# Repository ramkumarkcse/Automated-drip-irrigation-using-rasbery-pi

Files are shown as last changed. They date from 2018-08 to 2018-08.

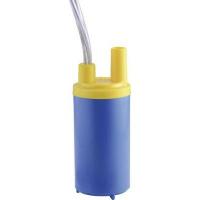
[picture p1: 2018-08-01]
images/water_pump_Barwig_BW04.jpg

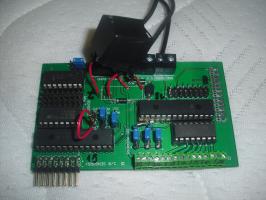
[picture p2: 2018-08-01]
images/pcb_sec_small.jpg

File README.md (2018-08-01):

# Automated-drip-irrigation-using-rasbery-pi
Introduction 

It is an automated system designed to take good care of your plants while you travel for a long time.The propose is to keep track of humidity levels and once in a while drip some water in your plants if they feel thirst. 

How the system works 

The concept is very simple, the system is composed by the following hardware:      

Arduino (I use the pro mini since it's tiny and you can weld according to your needs)      
Raspberry Pi as an interface to arduino (read sensors, upload new hex files if needed)      
Sensors      
Tiny pump      
Bucket with water      
Gardena micro dipping system      
Android phone to check the status of your plants 

The whole system is controlled by the arduino microcontroller. It checks the humidity sensors every cycle and sets a variable to true or false in case the sole conditions and amount of water on it. If it's dryi, according to a predefined threshold, it will drip water for few seconds or until the sole turns to hidratate enough.

How to use it

Import the Arduino file into an arduino IDE     
Import the android project to your IDE (I use eclipse)     
Copy the bridge file tcp_server.py into your raspberry Pi and set it up under your /etc/rc.local by adding the following line: (sleep 10;python /path/where/you/copied/tcp_server.py)&amp;

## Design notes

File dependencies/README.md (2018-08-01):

required dependencies fo YawsPi

in directory 'downloaded by pip' are packages downloaded by commad:
pip install --download="~" PACKAGENAME

file pygal.js-gh-pages.zip is downloaded form github, contains java scripts not required, but
usefull for nice pygal charts

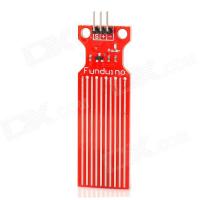
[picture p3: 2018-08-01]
images/water_level_sensor_funduino.jpg

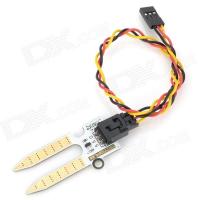
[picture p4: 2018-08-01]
images/water_level_sensor_octopus_soil_humidity.jpg

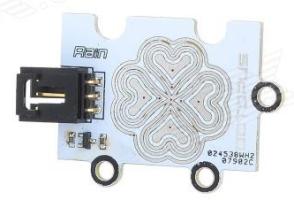
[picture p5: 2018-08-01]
images/rain_sensor_Octopus.jpg

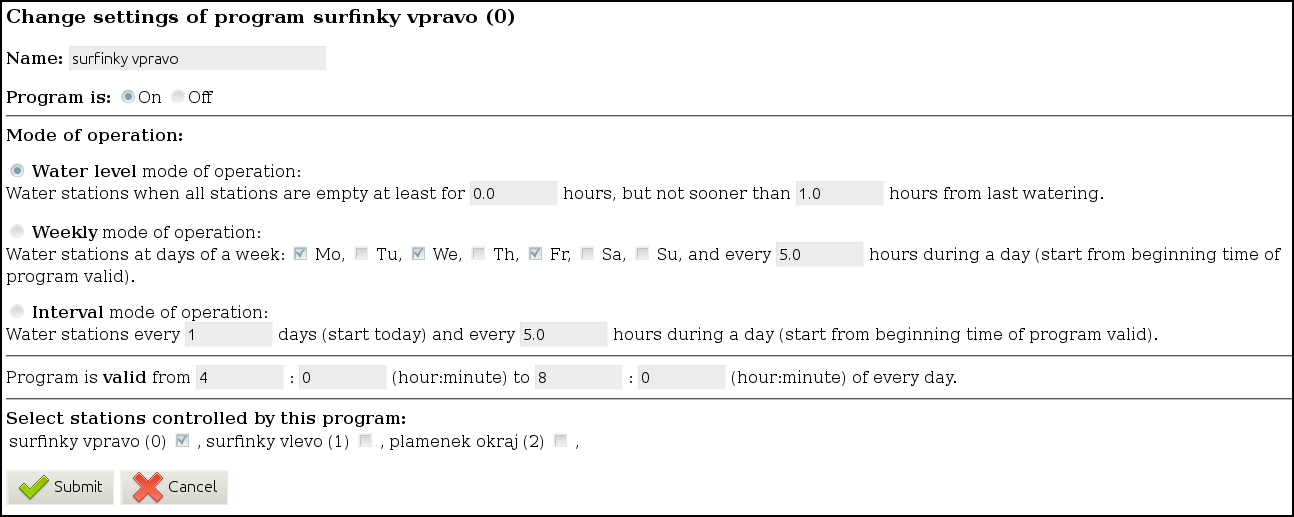
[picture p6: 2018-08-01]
images/webpage-programs-settings-brdr.png

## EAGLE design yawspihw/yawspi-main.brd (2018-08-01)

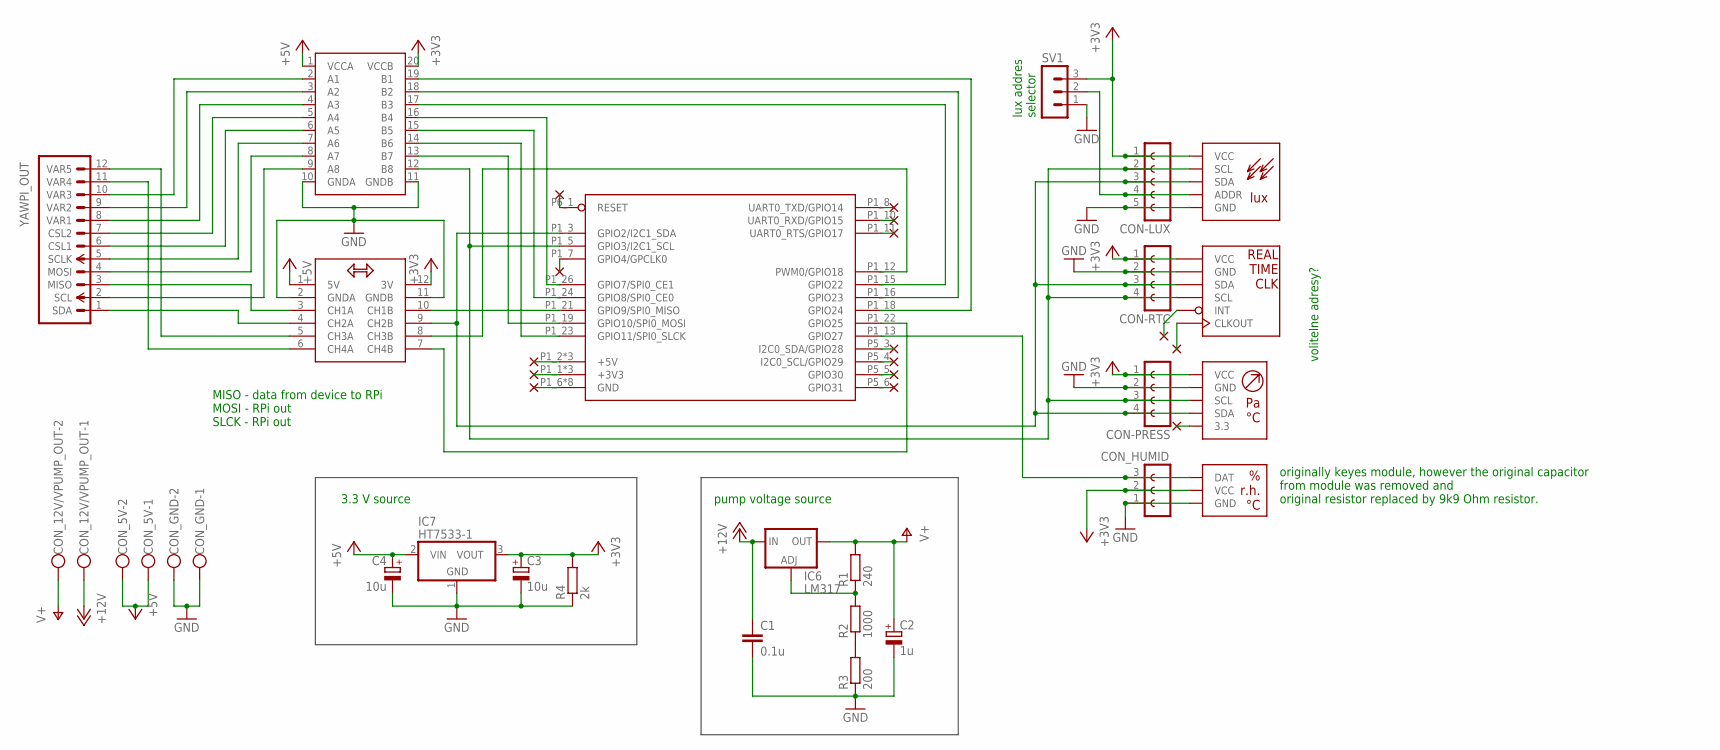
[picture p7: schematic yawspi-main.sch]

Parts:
C1: 0.1u; C025-025X050
C2: 1u; E2,5-6E
C3, C4: 10u; E2,5-5
CON-LUX: FE05-1
CON-PRESS: FE04-1
CON-RTC: FE04-1
CON_5V, CON_12V/VPUMP_OUT: W237-102
CON_GND: W237-102
CON_HUMID: FE03-1
IC6: LM317; 317TS
IC7: HT7533-1; TO92
R1: 240; 0204V
R2: 1000; 0204V
R3: 200; 0204V
R4: 2k; 0204V
SV1: MA03-1
U$1: RPI-B-V2HOLES; RPI-B-V2-HOLES
U$2: BIDIR_CONVERSION_MODULE
U$3: LEVEL_CONVERSION_MODULE
YAWPI_OUT: CON-YAWPI-OUT; MA12-1

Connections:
+3V3: C3.+, CON-LUX.1, CON-PRESS.1, CON-RTC.1, CON_HUMID.2, IC7.3 (VOUT), R4.2, SV1.3, U$2.12 (3V), U$3.20 (VCCB)
+5V: C4.+, CON_5V.1, CON_5V.2, IC7.2 (VIN), U$2.1 (5V), U$3.1 (VCCA)
+12V: C1.1, CON_12V/VPUMP_OUT.1, IC6.3 (IN)
GND: C1.2, C2.-, C3.-, C4.-, CON-LUX.5, CON-PRESS.2, CON-RTC.2, CON_GND.1, CON_GND.2, CON_HUMID.1, IC7.1 (GND), R3.1, R4.1, SV1.1, U$2.2 (GNDA), U$2.11 (GNDB), U$3.10 (GNDA), U$3.11 (GNDB)
MOSI: U$1.P1_19 (GPIO10/SPI0_MOSI), U$3.13 (B7)
unnamed: U$3.9 (A8), YAWPI_OUT.2 (SCL)
unnamed: U$3.6 (A5), YAWPI_OUT.6 (CSL1)
unnamed: U$2.4 (CH2A), YAWPI_OUT.1 (SDA)
unnamed: U$1.P1_21 (GPIO9/SPI0_MISO), U$2.10 (CH1B)
unnamed: U$3.7 (A6), YAWPI_OUT.5 (SCLK)
unnamed: U$3.8 (A7), YAWPI_OUT.4 (MOSI)
unnamed: U$2.3 (CH1A), YAWPI_OUT.3 (MISO)
unnamed: U$3.5 (A4), YAWPI_OUT.7 (CSL2)
unnamed: U$1.P1_12 (PWM0/GPIO18), U$2.8 (CH3B)
unnamed: U$1.P1_22 (GPIO25), U$2.7 (CH4B)
unnamed: U$3.4 (A3), YAWPI_OUT.8 (VAR1)
unnamed: U$3.3 (A2), YAWPI_OUT.9 (VAR2)
unnamed: U$3.2 (A1), YAWPI_OUT.10 (VAR3)
unnamed: U$2.6 (CH4A), YAWPI_OUT.11 (VAR4)
unnamed: U$2.5 (CH3A), YAWPI_OUT.12 (VAR5)
unnamed: U$1.P1_24 (GPIO8/SPI0_CE0), U$3.15 (B5)
unnamed: U$1.P1_26 (GPIO7/SPI0_CE1), U$3.16 (B4)
unnamed: U$1.P1_15 (GPIO22), U$3.17 (B3)
unnamed: U$1.P1_16 (GPIO23), U$3.18 (B2)
unnamed: U$1.P1_18 (GPIO24), U$3.19 (B1)
unnamed: CON_HUMID.3, U$1.P1_13 (GPIO27)
unnamed: U$1.P1_6 (GND), U$1.P1_9 (GND), U$1.P1_14 (GND), U$1.P1_20 (GND), U$1.P1_25 (GND), U$1.P5_7 (GND), U$1.P5_8 (GND), U$1.P6_2 (GND)
unnamed: CON-LUX.4, SV1.2
unnamed: U$1.P1_2 (+5V), U$1.P1_4 (+5V), U$1.P5_1 (+5V)
unnamed: U$1.P1_1 (+3V3), U$1.P1_17 (+3V3), U$1.P5_2 (+3V3)
unnamed: IC6.1 (ADJ), R1.1, R2.2
unnamed: R2.1, R3.2
SCL: CON-LUX.2, CON-PRESS.3, CON-RTC.4, U$1.P1_5 (GPIO3/I2C1_SCL), U$3.12 (B8)
SDA: CON-LUX.3, CON-PRESS.4, CON-RTC.3, U$1.P1_3 (GPIO2/I2C1_SDA), U$2.9 (CH2B)
SLCK: U$1.P1_23 (GPIO11/SPI0_SLCK), U$3.14 (B6)
V+: C2.+, CON_12V/VPUMP_OUT.2, IC6.2 (OUT), R1.2

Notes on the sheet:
3.3 V source
MISO - data from device to RPi MOSI - RPi out SLCK - RPi out
pump voltage source
volitelne adresy?
lux addres selector
originally keyes module, however the original capacitor from module was removed and original resistor replaced by 9k9 Ohm resistor.

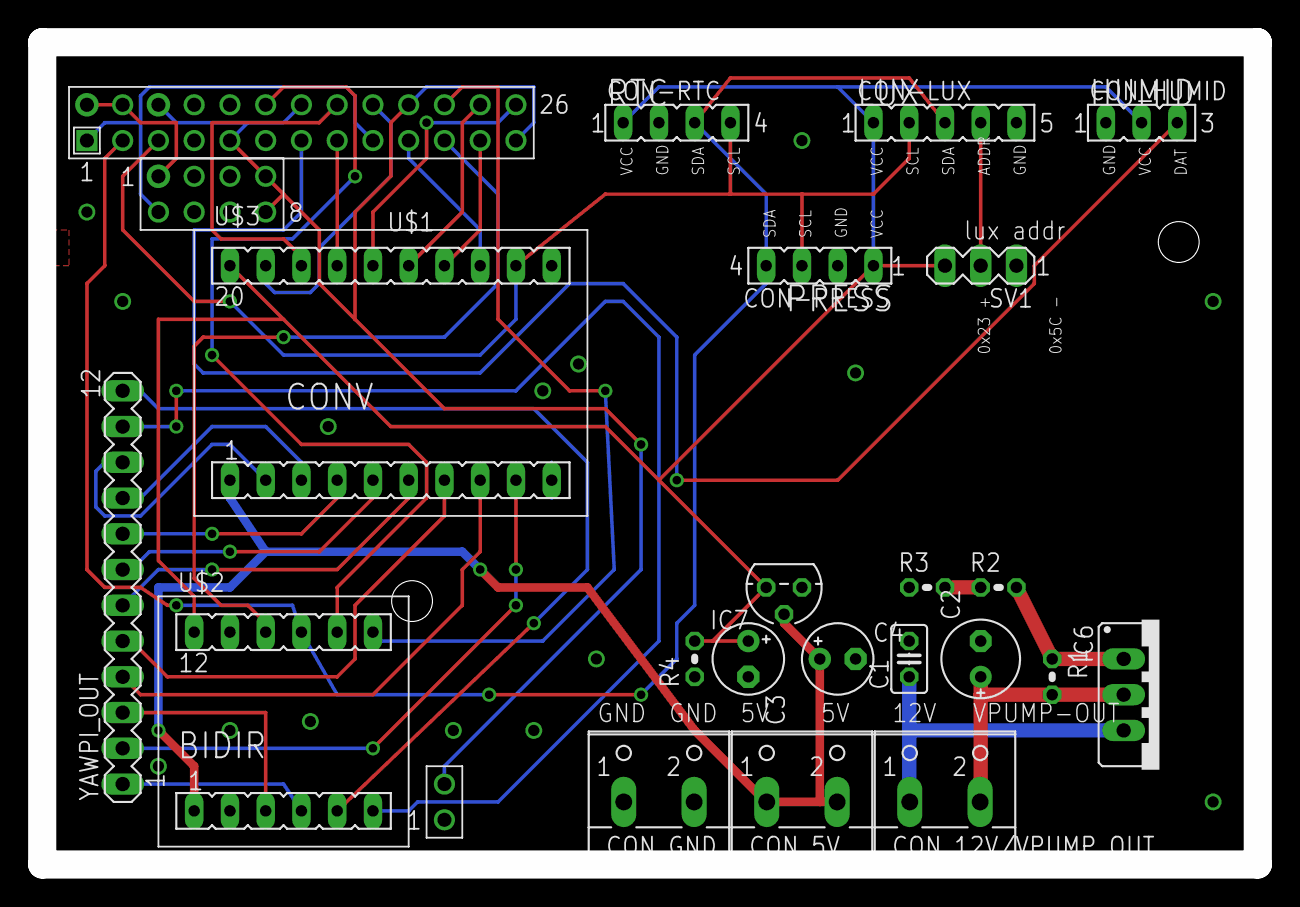
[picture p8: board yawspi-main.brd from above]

Board: 2 copper layers, 86.4 x 58.4 mm, 22 parts (0 on the bottom side), 36 nets.

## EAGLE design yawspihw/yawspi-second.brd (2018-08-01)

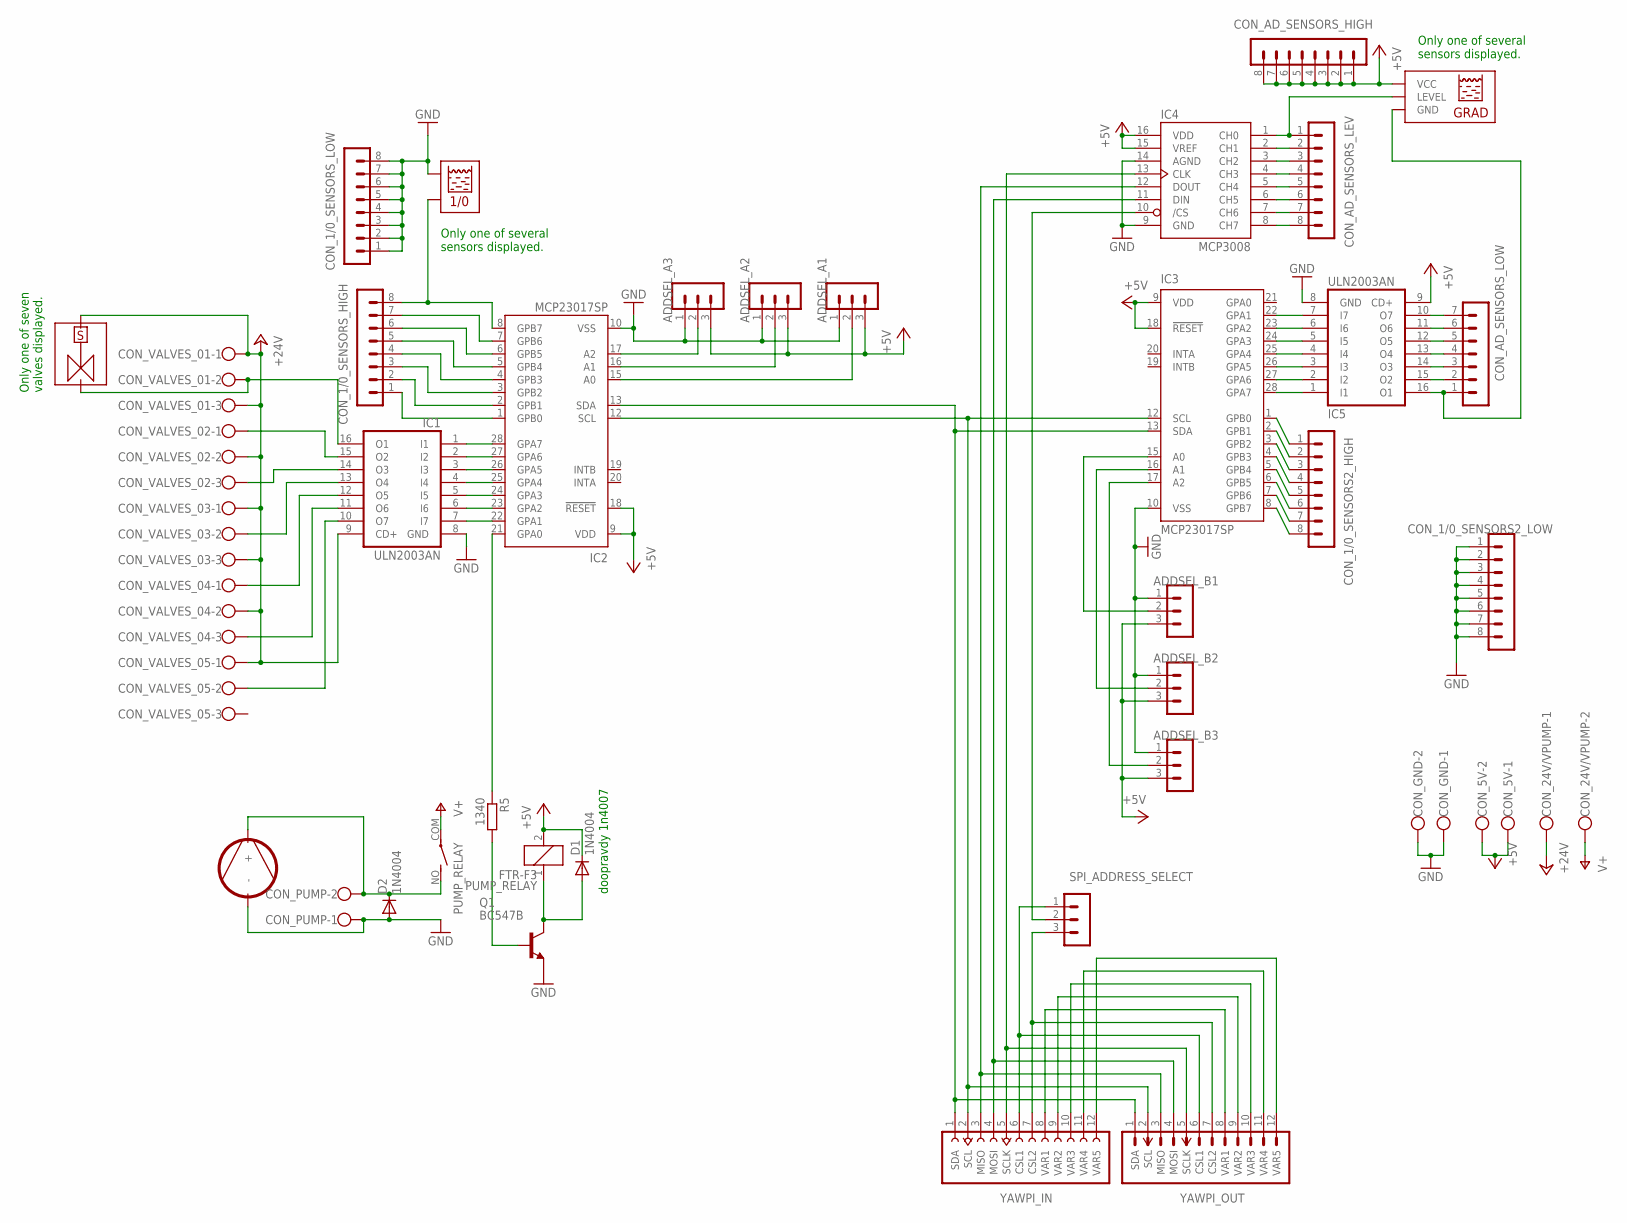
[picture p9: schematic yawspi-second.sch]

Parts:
ADDSEL_A1, ADDSEL_A2, ADDSEL_A3: MA03-1
ADDSEL_B1, ADDSEL_B2, ADDSEL_B3: MA03-1
CON_1/0_SENSORS2_HIGH, CON_1/0_SENSORS2_LOW, CON_1/0_SENSORS_HIGH, CON_1/0_SENSORS_LOW: MA08-1_SHORTPAD
CON_5V, CON_24V/VPUMP: W237-102
CON_AD_SENSORS_HIGH: MA08-1_SHORTPAD
CON_AD_SENSORS_LEV: MA08-1_SHORTPAD
CON_AD_SENSORS_LOW: MA07-1_SHORTPAD
CON_GND: W237-102
CON_PUMP: W237-102
CON_VALVES_01, CON_VALVES_02, CON_VALVES_03, CON_VALVES_04, CON_VALVES_05: W237-102-SMALL
D1, D2: 1N4004; DO41-10
IC1, IC5: ULN2003AN; DIL16
IC2, IC3: MCP23017SP; DIL28-3
IC4: MCP3008; DIL16
PUMP_RELAY: FTR-F3; FTR-F3_PACKAGE
Q1: BC547B; TO92
R5: 1340; 0204/7
SPI_ADDRESS_SELECT: MA03-1
YAWPI_IN: CON-YAWPI-IN; FE12
YAWPI_OUT: CON-YAWPI-OUT; MA12-1

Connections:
+5V: ADDSEL_A1.3, ADDSEL_A2.3, ADDSEL_A3.3, ADDSEL_B1.3, ADDSEL_B2.3, ADDSEL_B3.3, CON_5V.1, CON_5V.2, CON_AD_SENSORS_HIGH.1, CON_AD_SENSORS_HIGH.2, CON_AD_SENSORS_HIGH.3, CON_AD_SENSORS_HIGH.4, CON_AD_SENSORS_HIGH.5, CON_AD_SENSORS_HIGH.6, CON_AD_SENSORS_HIGH.7, CON_AD_SENSORS_HIGH.8, D1.C, IC2.9 (VDD), IC2.18 (!RESET), IC3.9 (VDD), IC3.18 (!RESET), IC4.15 (VREF), IC4.16 (VDD), IC5.9 (CD+), PUMP_RELAY.2
+24V: CON_24V/VPUMP.1, CON_VALVES_01.1, CON_VALVES_01.3, CON_VALVES_02.2, CON_VALVES_03.1, CON_VALVES_03.3, CON_VALVES_04.2, CON_VALVES_05.1, IC1.9 (CD+)
GND: ADDSEL_A1.1, ADDSEL_A2.1, ADDSEL_A3.1, ADDSEL_B1.1, ADDSEL_B2.1, ADDSEL_B3.1, CON_1/0_SENSORS2_LOW.1, CON_1/0_SENSORS2_LOW.2, CON_1/0_SENSORS2_LOW.3, CON_1/0_SENSORS2_LOW.4, CON_1/0_SENSORS2_LOW.5, CON_1/0_SENSORS2_LOW.6, CON_1/0_SENSORS2_LOW.7, CON_1/0_SENSORS2_LOW.8, CON_1/0_SENSORS_LOW.1, CON_1/0_SENSORS_LOW.2, CON_1/0_SENSORS_LOW.3, CON_1/0_SENSORS_LOW.4, CON_1/0_SENSORS_LOW.5, CON_1/0_SENSORS_LOW.6, CON_1/0_SENSORS_LOW.7, CON_1/0_SENSORS_LOW.8, CON_GND.1, CON_GND.2, CON_PUMP.1, D2.A, IC1.8 (GND), IC2.10 (VSS), IC3.10 (VSS), IC4.9 (GND), IC4.14 (AGND), IC5.8 (GND), Q1.1 (E)
unnamed: D1.A, PUMP_RELAY.1, Q1.3 (C)
unnamed: IC3.28 (GPA7), IC5.1 (I1)
unnamed: IC1.7 (I7), IC2.22 (GPA1)
unnamed: IC1.6 (I6), IC2.23 (GPA2)
unnamed: IC1.5 (I5), IC2.24 (GPA3)
unnamed: IC1.4 (I4), IC2.25 (GPA4)
unnamed: IC1.3 (I3), IC2.26 (GPA5)
unnamed: IC1.2 (I2), IC2.27 (GPA6)
unnamed: IC1.1 (I1), IC2.28 (GPA7)
unnamed: IC4.12 (DOUT), YAWPI_IN.3 (MISO), YAWPI_OUT.3 (MISO)
unnamed: IC2.13 (SDA), IC3.13 (SDA), YAWPI_IN.1 (SDA), YAWPI_OUT.1 (SDA)
unnamed: CON_VALVES_01.2, IC1.16 (O1)
unnamed: IC2.12 (SCL), IC3.12 (SCL), YAWPI_IN.2 (SCL), YAWPI_OUT.2 (SCL)
unnamed: IC3.27 (GPA6), IC5.2 (I2)
unnamed: CON_AD_SENSORS_LEV.1, IC4.1 (CH0)
unnamed: CON_VALVES_02.1, IC1.15 (O2)
unnamed: CON_VALVES_05.2, IC1.10 (O7)
unnamed: CON_VALVES_02.3, IC1.14 (O3)
unnamed: CON_VALVES_03.2, IC1.13 (O4)
unnamed: CON_VALVES_04.1, IC1.12 (O5)
unnamed: CON_1/0_SENSORS_HIGH.1, IC2.1 (GPB0)
unnamed: IC3.26 (GPA5), IC5.3 (I3)
unnamed: IC4.11 (DIN), YAWPI_IN.4 (MOSI), YAWPI_OUT.4 (MOSI)
unnamed: CON_VALVES_04.3, IC1.11 (O6)
unnamed: CON_1/0_SENSORS_HIGH.7, IC2.7 (GPB6)
unnamed: CON_1/0_SENSORS_HIGH.6, IC2.6 (GPB5)
unnamed: CON_1/0_SENSORS_HIGH.5, IC2.5 (GPB4)
unnamed: CON_1/0_SENSORS_HIGH.4, IC2.4 (GPB3)
unnamed: CON_1/0_SENSORS_HIGH.3, IC2.3 (GPB2)
unnamed: CON_1/0_SENSORS_HIGH.2, IC2.2 (GPB1)
unnamed: IC3.25 (GPA4), IC5.4 (I4)
unnamed: IC3.24 (GPA3), IC5.5 (I5)
unnamed: CON_AD_SENSORS_LEV.2, IC4.2 (CH1)
unnamed: CON_AD_SENSORS_LEV.3, IC4.3 (CH2)
unnamed: CON_AD_SENSORS_LEV.4, IC4.4 (CH3)
unnamed: CON_AD_SENSORS_LEV.5, IC4.5 (CH4)
unnamed: CON_AD_SENSORS_LEV.6, IC4.6 (CH5)
unnamed: CON_AD_SENSORS_LEV.7, IC4.7 (CH6)
unnamed: CON_AD_SENSORS_LEV.8, IC4.8 (CH7)
unnamed: IC3.23 (GPA2), IC5.6 (I6)
unnamed: IC3.22 (GPA1), IC5.7 (I7)
unnamed: CON_1/0_SENSORS2_HIGH.8, IC3.8 (GPB7)
unnamed: CON_1/0_SENSORS2_HIGH.7, IC3.7 (GPB6)
unnamed: CON_1/0_SENSORS2_HIGH.6, IC3.6 (GPB5)
unnamed: CON_1/0_SENSORS2_HIGH.5, IC3.5 (GPB4)
unnamed: CON_1/0_SENSORS2_HIGH.4, IC3.4 (GPB3)
unnamed: CON_1/0_SENSORS2_HIGH.3, IC3.3 (GPB2)
unnamed: CON_1/0_SENSORS2_HIGH.2, IC3.2 (GPB1)
unnamed: CON_1/0_SENSORS2_HIGH.1, IC3.1 (GPB0)
unnamed: IC4.10 (/CS), SPI_ADDRESS_SELECT.2
unnamed: IC4.13 (CLK), YAWPI_IN.5 (SCLK), YAWPI_OUT.5 (SCLK)
unnamed: CON_AD_SENSORS_LOW.2, IC5.15 (O2)
unnamed: CON_AD_SENSORS_LOW.3, IC5.14 (O3)
unnamed: CON_AD_SENSORS_LOW.4, IC5.13 (O4)
unnamed: CON_AD_SENSORS_LOW.5, IC5.12 (O5)
unnamed: CON_AD_SENSORS_LOW.6, IC5.11 (O6)
unnamed: CON_AD_SENSORS_LOW.7, IC5.10 (O7)
unnamed: Q1.2 (B), R5.2
unnamed: ADDSEL_A3.2, IC2.17 (A2)
unnamed: SPI_ADDRESS_SELECT.3, YAWPI_IN.7 (CSL2), YAWPI_OUT.7 (CSL2)
unnamed: IC2.21 (GPA0), R5.1
unnamed: CON_1/0_SENSORS_HIGH.8, IC2.8 (GPB7)
unnamed: YAWPI_IN.8 (VAR1), YAWPI_OUT.8 (VAR1)
unnamed: YAWPI_IN.9 (VAR2), YAWPI_OUT.9 (VAR2)
unnamed: YAWPI_IN.10 (VAR3), YAWPI_OUT.10 (VAR3)
unnamed: CON_PUMP.2, D2.C, PUMP_RELAY.NO (S)
unnamed: SPI_ADDRESS_SELECT.1, YAWPI_IN.6 (CSL1), YAWPI_OUT.6 (CSL1)
unnamed: ADDSEL_A2.2, IC2.16 (A1)
unnamed: ADDSEL_A1.2, IC2.15 (A0)
unnamed: ADDSEL_B1.2, IC3.15 (A0)
unnamed: ADDSEL_B2.2, IC3.16 (A1)
unnamed: ADDSEL_B3.2, IC3.17 (A2)
unnamed: YAWPI_IN.11 (VAR4), YAWPI_OUT.11 (VAR4)
unnamed: YAWPI_IN.12 (VAR5), YAWPI_OUT.12 (VAR5)
P$2: CON_AD_SENSORS_LOW.1, IC5.16 (O1)
V+: CON_24V/VPUMP.2, PUMP_RELAY.COM

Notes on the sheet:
Only one of seven valves displayed.
Only one of several sensors displayed.
doopravdy 1n4007

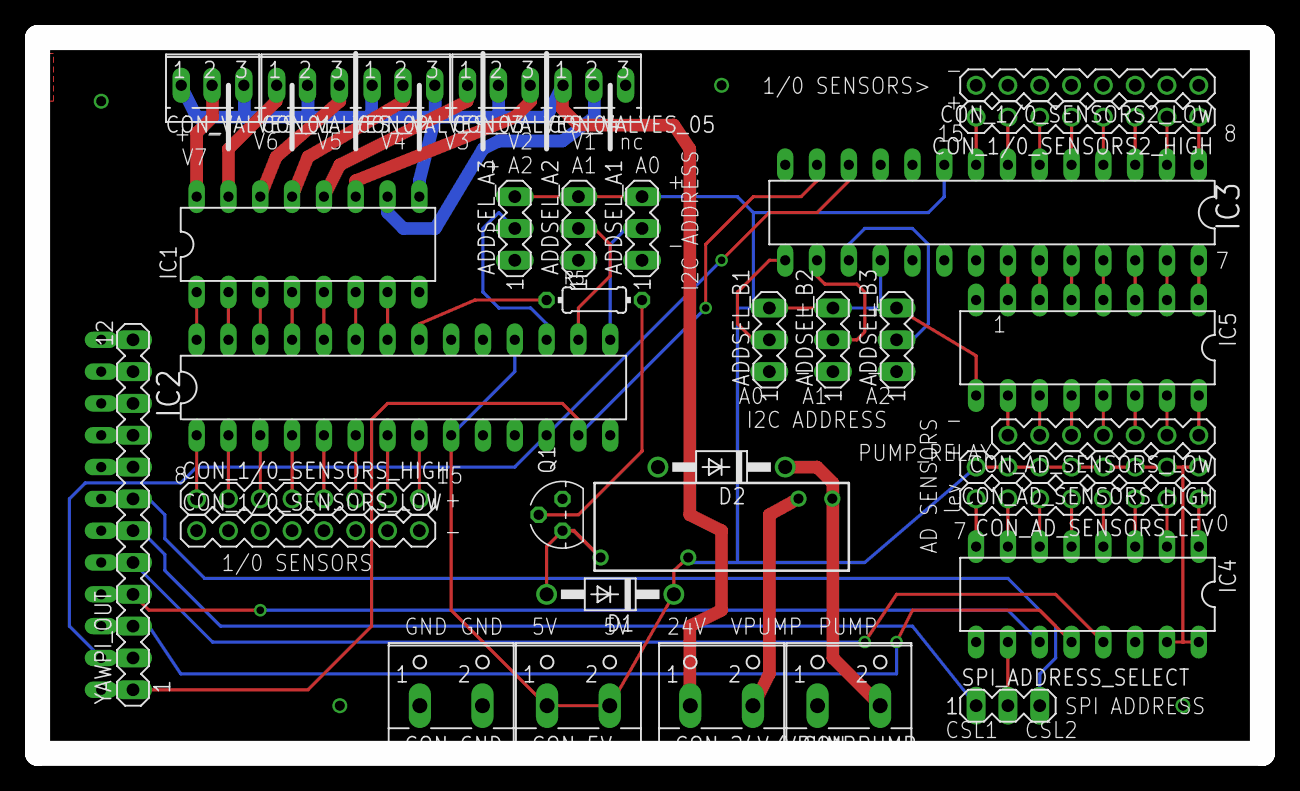
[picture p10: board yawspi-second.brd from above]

Board: 2 copper layers, 97.8 x 57.1 mm, 35 parts (1 on the bottom side), 79 nets.

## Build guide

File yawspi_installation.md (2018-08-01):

Installation of yawspisw on a fresh sd card
===
1. [download Jessie lite](https://www.raspberrypi.org/downloads/raspbian/)
1. check checksum
1. unzip
1. install according
[help](https://www.raspberrypi.org/documentation/installation/installing-images/linux.md)
    sudo dd bs=4M if=2016-05-27-raspbian-jessie-lite.img of=/dev/mmcblk0
1. sync:
    sync
1. put SD card into raspberry, connect ethernet, switch on power source, wait a little
1. find out ip address of rapsberry
1. login:
    ssh pi@ip.address.of.raspberry
1. run
    sudo raspi-config
and expand the filesystem to whole image. reboot.
1. login, run raspi-config again, set hostname to *yawspi*, enable SPI and I2C, 
1. install wicd (and remove dhcpcd5 to remove conflicts) for wifi:
    sudo apt-get update
    sudo apt-get remove dhcpcd5
    sudo apt-get install wicd-curses
run wicd-curses and setup your wifi, disconnect ethernet and test wifi connection
1. install git:
    sudo apt-get install git
1. pull yawspi git:
    git clone https://github.com/KaeroDot/YawsPi.git
1. install yawspi dependencies:
    sudo apt-get install python-arrow python-webpy python-smbus
    sudo pip install pygal
1. cd to YawsPi/yawspisw/, edit hw_config.py according the hardware configuration
1. cd to YawsPi/yawspisw/ and run following to check everything is ok:
    python yawspisw.py 
1. copy yawspisw.service in yawspisw directory to /lib/systemd/system:
    sudo mv yawspi.service /lib/systemd/system
1. check that permissions are 644:
    sudo chmod 644 /lib/systemd/system/yawspi.service
1. reload daemons in systemd:
    sudo systemctl daemon-reload
1. enable the yawspi sservice:
    sudo systemctl enable yawspi.service
1. reboot and check yawspi is running:
    sudo reboot
1. there should be running yawspi webpage at 
    http://ip.address.of.raspberry:8080

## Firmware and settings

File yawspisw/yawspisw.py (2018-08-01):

#!/usr/bin/env python
# -*- coding: utf-8 -*-
#
# vim modeline: vim: shiftwidth=4 tabstop=4
#=================================================================
# main yawspi program
#=================================================================

# XXX todo:
# bugs:
# 3, station settings - threshold - does it change grad sensor slope? should
# it? recalculate values to 0..1?
# 6, ensure the smallest main loop time is one minute otherwise looking for
# next running times could fail - really?
# 7, show webpage 'wait' if user wants water station NOW from stations web
# page?
# 8, home page, table programs: when 'next run in' is now, nothing is
# shown
# 9, kdyz ukladani hladin do specialniho souboru, zrusit zapis do logu?
# 10, pred zacatkem napousteni zmerit hodnotu sensoru jestli neni plna stanice
# 11, po skonceni plneni upravit hodnoty pro web
# 13, YawspiHW prejmenovat na YawspiHAL, hw_control na HAL.py
# 14, kdyz se da water station now (z web stations), tak da status filling, pak
# kdyz se da casem refresh page, tak ukaze ze skoncil filling, ale senzor ma
# spatny stav, na to se musi dat check now. coz je napytel, protoze po filling
# uz musi mit senzor zmereny ne?
# 17, program water by level ignoruje cas platnosti programu
# 18, 'Desc': gv.hw.se_description(x) is updated only once during
# initialization

# standard modules:
from time import sleep
import arrow
import signal
import sys
import web
import thread
import pickle
import os
import pygal
# gv - 'global vars' - an empty module, used for storing vars (as attributes),
# that need to be 'global' across threads and between functions and classes:
import gv
# yawspi hardware control (hardware abstraction layer):
from hw_control import YawspiHW


# ------------------- various functions:
def sigterm_handler(_signo, _stack_frame):
    # Raises SystemExit(0):
    sys.exit(0)


def get_now_str_web():  # returns current date/time as string for home web page
    """ return current date and time as string for web

    Format is
    DD. MM. YYYY HH:MM:ss, dddd, MMMM, ZZ
    e.g. 2015 13:35:40, wednesday, january, +01
    \param Nothing
    \return string: date and time as string
    """
    return arrow.now('local').format('DD. MM. YYYY HH:mm:ss, dddd, MMMM, ZZ')


def quit(reason):  # performs safe quit
    """ perform safe quit of the YAWSPI

    1. switch water source off,
    2. switch valves off,
    3. release GPIO,
    4. save configuration, programs, hardware settings
    5. write quitting to log
    6. save log
    \param string: reason why quitting
    \return Nothing
    """
    gv.hw.so_switch(0)  # set water source off
    for i in range(gv.hw.StNo):
        gv.hw.st_switch(i, 0)  # switch valve off
    gv.hw.clean_up()  # cleans GPIO
    gs_save()  # save configuration
    prg_save()  # save programs
    hws_save()  # save hardware settings
    log_add('quitting, ' + reason)
    log_save()  # save log


def td_format(td_object):  # formats timedelta to nice string
        """ formats timedelta object to a nice string

        Format is in human readable form
        \param timedelta: difference of two arrow or datetime objects
        \return string: time difference as string
        """
        seconds = int(td_object.total_seconds())
        periods = [
            ('year',        60 * 60 * 24 * 365),
            ('month',       60 * 60 * 24 * 30),
            ('day',         60 * 60 * 24),
            ('hour',        60 * 60),
            ('minute',      60),
        ]
            #('second',      1)
        strings = []
        for period_name, period_seconds in periods:
                if seconds > period_seconds:
                        period_value, seconds = divmod(seconds, period_seconds)
                        if period_value == 1:
                                strings.append("%s %s" %
                                               (period_value, period_name)
                                               )
                        else:
                                strings.append("%s %ss" %
                                               (period_value, period_name)
                                               )
        return ", ".join(strings)


def check_and_set_time():  # check local and RTC time
    """
    Every week check local and RTC time and set one.

    If local time is smaller than 1.1.2000, set local according to RTC, else
    set RTC according local. It is done only once per week. Also checks RTC
    battery.
    \param None
    \return None
    """
    # check if last check was done at least one week before:
    if arrow.utcnow().replace(weeks=-1) > gv.lastRTCupdate:
        lcl = arrow.utcnow()
        if not gv.hw.RTC_get_bat():
            log_add(' <font color="red">RTC battery not OK!</font>')
        if lcl < arrow.get(2000, 1, 1):
            # update local time
            gv.hw.RTC_set_local()
            log_add('local time updated from RTC')
        else:
            # update RTC time
            gv.hw.RTC_set_RTC()
            log_add('RTC time updated from local')
        gv.lastRTCupdate = lcl


# ------------------- variables initializations/definitions:
def init_gs():  # initialize dictionary with general settings:
    """ initialize global variable gv.gs dictionary

    gv.gs contains basic settings of YAWSPI software:
    1. Name: configurable name of the system
    2. Version: yawspi version
    3. Enabled: operation enabled
    4. httpPort: http listening port of web server
    5. Location: city name for weather retrieval from internet \todo{not
        finished} XXX
    6. Logging: writing to log enabled
    7. LoggingLimit: maximal number of log lines to keep, 0 = no limit
    8. MLInterval: Main loop interval (s) - how often watering and water levels
        are checked.
    \param Nothing
    \return Nothing
    """
    gv.gs = {
        'Name': u'YAWSPI',
        'Version': u'0.1',
        'Enabled': True,
        'httpPort': 8080,
        'Location': u'Brno',
        'Logging': True,
        'LoggingLimit': 1000,
        'MLInterval': 60
    }


def init_hws():  # initialize dictionary with hw settings:
    """ Initialize global variable gv.hws dictionary with hardware data.

    gv.hws contains hardware related values, which can be mostly set by
    webserver:
    1. StData: list of dictionaries containing:
        1. Name: Station name
        2. LowThr: lower threshold - if sensors value is below, station is
        considered empty
        3. HighThr: upper threshold - if sensors value is above, station is
        considered full
        4. SaveData: boolean whether save measured and filling data
        5. Desc: sensor description generated by hardware abstraction layer
    2. SoData: dictionary containing:
        1. SaveData: boolean whether save measured data
    3. SeData: list of dictionaries containing:
        1. SaveData: ??? XXX
    \param Nothing
    \return Nothing
    \todo{check if SeData SaveData is not duplicit, and what is the difference
    to StData SaveData}
    """
    gv.hws = {
        'StData': [],
        'SoData': {
            'SaveData': True,
        },
        'SeData': {
            'SaveData': [],
        },
    }
    for x in range(gv.hw.StNo):
        gv.hws['StData'].append({
            'Name': 'station ' + str(x),
            'LowThr': 0.1,
            'HighThr': 0.9,
            'SaveData': True,
            'Desc': gv.hw.se_description(x)
        })


def init_cv():  # initialize dictionary with current values
    """ initialize global variable gv.cv dictionary with various current values

    gv.cv values are generated by some funtction and contains:
    1. TimeStr: current time as string for webpage generated by get_now_str_web
    2. SoWL: current water level of source
    3. StWL: list of numbers with current water level of stations
    4. PrgNR: list of arrow objects with next watering times of programs
    5. SeTemp: temperature weather sensor value
    6. SeRain: rain weather sensor value
    7. SeHumid: humidity weather sensor value
    8. SePress: pressure weather sensor value
    9. SeIllum: illuminance weather sensor value
    10. CurAct: what is software now doing
    11. xConstrain: x axis in history chart is constrained to xMin and xMax
    11. xMin: arrow time last shown x minimal value in history chart
    12. xMax: arrow time last shown x maximal value in history chart
    \param Nothing
    \return Nothing
    """
    gv.cv = {
        'TimeStr': get_now_str_web(),
        'SoWL': 0,
        'StWL': [0] * gv.hw.StNo,
        'PrgNR': [arrow.now('local')] * len(gv.prg),
        'SeTemp': -300,
        'SeRain': -300,
        'SeHumid': -300,
        'SePress': -300,
        'SeIllum': -300,
        'CurAct': '',
        'xConstrain': False,
        'xMin': arrow.now('local').replace(days=-2),
        'xMax': arrow.now('local'),
    }


def prg_get_new():  # returns dict with a new program
    """ return dictionary with a new program

    program dictionary contains:
    1. Name: string name of the program
    2. Enabled: boolean program is enabled
    3. Stations: list of stations numbers affected by program
    4. Mode: string mode of operation, possible values:
        1. waterlevel: according water level - start if all stations empty
        2. weekly: according calendar - start selected days of week
        3. interval: according calendar - start every nth day
    5. wlMinDelayH: integer, for waterlevel mode - not start sooner than
    (hours)
    6. wlEmptyDelayH, integer, for waterlevel mode - must be empty at least
    (hours)
    7. calwDays: list of integers, for weekly mode - start days in week (1 -
    Monday, 7 - Sunday):
    8. calwRepeatH: integer, for weekly mode - repeat during day every (hours):
    9. caliIntervalD: integer, for interval mode - repeat interval (days):
    10. caliRepeatH: integer, for interval mode - repeat during day every
    (hours):
    11. TimeFromH: integer, program valid from time of day (Hours):
    12. TimeFromM: integer, program valid from time of day (Minutes):
    13. TimeToH: integer, program valid to time of day (Hours):
    14. TimeToM: integer, program valid to time of day (Minutes):
    15. TimeLastRun: arrow, last run of program (for a new program is set 1 day
    to the past - i.e. equal to caliIntervalD
    16. FoundEmpty: boolean, all stations of the program was already found as
    empty? (for a new program is set as not yet found empty (False))
    17. TimeFoundEmpty: arrow, first time when found all stations of the
    program empty (usefull only for waterlevel mode, is used only if
    'FoundEmpty' is True)
    \param Nothing
    \return dict: default program dictionary
    """
    return {
        'Name': 'new program',
        'Enabled': False,
        'Stations': [],
        #'Mode': 'waterlevel',
        #'Mode': 'weekly',
        'Mode': 'interval',
        'wlMinDelayH': 1,
        'wlEmptyDelayH': 1,
        'calwDays': [1, 3, 5],
        'calwRepeatH': 5,
        'caliIntervalD': 1,
        'caliRepeatH': 5,
        'TimeFromH': 6,
        'TimeFromM': 0,
        'TimeToH': 19,
        'TimeToM': 0,
        'TimeLastRun': arrow.now('local').replace(days=-1),
        'FoundEmpty': False,
        'TimeFoundEmpty': arrow.now('local')
    }


# ------------------- watering program handling:
def prg_add():  # add a new program
    """ add a new program to the list of programs

    new program with default values is appended to the gv.prg and gv.cv is
    updated.
    \param Nothing
    \return Nothing
    """
    # append new program:
    gv.prg.append(prg_get_new())
    # increase list with next watering time for web server:
    gv.cv['PrgNR'].append(arrow.now('local'))


def prg_remove(index):  # remove a program
    """ remove a program from the list of programs

    remove program of index, update gv.cv
    \param index: integer of the program to remove
    \return Nothing
    """
    # remove program:
    gv.prg.pop(index)
    # decrease list with next watering time for web server:
    gv.cv['PrgNR'].pop(index)


def prg_is_water_time(index):  # return boolean if watering should start
    """ finds if watering should start

    Checks if program is enabled, than according program mode asks for watering
    time later than now. Checks if watering time is_in_time_span. Adds log if
    watering should start or not and why not

    \param int: index of the program
    \return bool: True if watering is due
    """
    prg = gv.prg[index]
    now = arrow.now('local')
    if not prg['Enabled']:
        # disabled program is not logged
        return False
    else:
        # if source empty, no action:
        if gv.cv['SoWL'] == 0:
            log_add('program "' + prg['Name'] +
                    '" (' + str(index) + '): ' +
                    'not ready for watering, source is empty!'
                    )
            return False
        now = arrow.now('local')
        isreadystr = 'program "' + prg['Name'] + \
                     '" (' + str(index) + '): ready for watering'
        notreadystr = 'program "' + prg['Name'] + '" (' + str(index) + '): '
        if prg['Mode'] == 'waterlevel':
            # water level mode:
            tmp = prg_lev_is_water_time(index, now)
            # next run not available in water level mode, string for web:
            tim = tmp[0] - arrow.now('local')
            if tim.total_seconds() < 0:
                gv.cv['PrgNR'][index] = 'Not yet empty'
            else:
                gv.cv['PrgNR'][index] = td_format(tim)
            if tmp[2]:
                log_add(isreadystr)
                return True
            else:
                log_add(notreadystr + tmp[1])
                return False
        elif prg['Mode'] == 'weekly':
            # weekly calendar mode:
            tmp = prg_wee_next_water_time(index, now)
            # generate next run in string for web:
            gv.cv['PrgNR'][index] = td_format(tmp[0] - arrow.now('local'))
            if is_in_time_span(index, now, tmp[0]):
                log_add(isreadystr)
                return True
            else:
                log_add(notreadystr + tmp[1])
                return False
        elif prg['Mode'] == 'interval':
            # interval mode:
            tmp = prg_int_next_water_time(index, now)
            # generate next run in string for web:
            gv.cv['PrgNR'][index] = td_format(tmp[0] - arrow.now('local'))
            if is_in_time_span(index, now, tmp[0]):
                log_add(isreadystr)
                return True
            else:
                log_add(notreadystr + tmp[1])
                return False
        else:
            raise NameError('unknown program type')


def prg_lev_is_water_time(index, now):  # checks if is watering time
    """ Checks if now is watering time for water level mode progam.

    Checks if all stations are empty, if so set FoundEmpty to True, if not set
    to False (also sets TimeFoundEmpty). Set to False is because if pot is
    found empty, and program waits some time, and someone waters it in between,
    than program would water even if stations are full.
    Than checks time from last watering and if time from found empty is long
    enough.

    \param int: index of program
    \param arrow: time after which next watering time is found
    \return tuple: (bool, string, arrow), bool True if program is ready for
    watering; string with description why program is not ready for watering if
    so; arrow time of next watering if possible, if not reutrn time smaller
    than input parameter
    """
    prg = gv.prg[index]
    # check if all stations in program are empty:
    # If FoundEmpty is false, routine still did not found all stations to be
    # empty
    allempty = True
    for st in prg['Stations']:
        # station is empty if value is lower than low threshold:
        if gv.cv['StWL'][st] > gv.hws['StData'][st]['LowThr']:
            allempty = False
    if not allempty:
        # return time in history to represent that it is impossible to know
        # when next watering will be
        tmp = now.replace(days=-1)
        # someone other could water the pot instead of YawsPi, so just to be
        # sure FoundEmpty is reseted:
        gv.prg[index]['FoundEmpty'] = False
        return (tmp, 'some stations still not empty', False)
    else:
        if prg['FoundEmpty'] is False:
            # all stations found empty for first time, remember time:
            gv.prg[index]['TimeFoundEmpty'] = now
            # and set it was already found empty:
            gv.prg[index]['FoundEmpty'] = True
    # stations found empty, so:
    # check if time from last watering is long enough:
    tmp = prg['TimeLastRun'].replace(hours=prg['wlMinDelayH'])
    if now <= tmp:
        return (tmp, 'not long enough from last watering', False)
    # check if stations are empty long enough:
    tmp = prg['TimeFoundEmpty'].replace(hours=prg['wlEmptyDelayH'])
    if now < tmp:
        return (tmp, 'stations not empty long enough', False)
    # all conditions ok, program is ready for watering:
    return (now, 'ready for watering', True)


def is_in_time_span(index, querytime, nextwatertime):  # times are equal?
    """ Checks if two times are equal within precision given by main loop
    interval gv.gs['MLInterval'].

    Precision is two times of mail loop interval (MLI).
    So True is returned if:
        1, querytime is later than TimeLastRun + 2*MLI
        1, querytime is later than nextwatertime - 2*MLI
        1, querytime is earlier than nextwatertime + 2*MLI

    \param int: index of program
    \param arrow: querytime is time for which should be determined if it is
    watering time
    \param arrow: nextwatertime is watering time later than query time
    \return bool: True if times equal
    """
    mli = gv.gs['MLInterval']
    tlr = gv.prg[index]['TimeLastRun']
    tmp = (
        querytime > tlr.replace(seconds=2 * mli)
        and
        nextwatertime > querytime.replace(seconds=-2 * mli)
        and
        nextwatertime < querytime.replace(seconds=+2 * mli)
    )
    return tmp


def prg_wee_next_water_time(index, starttime):  # returns next watering time
    """ Returns next watering time for program with weekend mode.

    Search for next watering time starts from starttime.
    \param int: index of program
    \param arrow: starttime after which next watering time is found
    \return tuple: (arrow, string), time of next watering, string with
    description why now is not next watering (in the case it is not).
    """
    prg = gv.prg[index]
    # check variables to prevent infinite while loops:
    if not bool(set(prg['calwDays']) & set(range(1, 8))):
        raise NameError('program does not contain any valid weekdays!')
    if not prg['calwRepeatH'] > 0:
        raise NameError('program repeat hour is not greater than zero!')
    reason = 'not valid day of week'
    # prepare time pointer
    t = starttime
    t = t.replace(hour=prg['TimeFromH'], minute=prg['TimeFromM'])
    t = t.floor('minute')
    # is t (same day as starttime) the valid week day?
    if t.isoweekday() in prg['calwDays']:
        ts = t
        # starttime is valid week of day,
        # add repeat interval till bigger than starttime:
        while not ts >= starttime:
            ts = ts.replace(hours=prg['calwRepeatH'])
        # if ts is still the same day as starttime:
        if ts.day == t.day:
            # if not later than 'program valid to' time:
            pvt = ts.replace(hour=prg['TimeToH'], minute=prg['TimeToM'])
            pvt = pvt.floor('minute')
            if ts <= pvt:
                # time of next watering time found, if ts is not the same as
                # starttime, only reason can be:
                reason = 'not valid time of a day'
                return (ts, reason)
        # date overflow, therefore starttime is later than TimeTo:
        reason = 'later than TimeTo'
        # add day and continue looking for valid weekday:
        t = t.replace(days=+1)
    # t is not valid weekday, add days till next valid weekday found:
    while not t.isoweekday() in prg['calwDays']:
        t = t.replace(days=+1)
    # set hour and minute to 'program valid from'
    return (t, reason)
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

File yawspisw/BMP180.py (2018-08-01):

#!/usr/bin/python
# -*- coding: utf-8 -*-

# library for pressure/temperature sensro BMP180 over i2c bus

# based on the script from astromik.org, all credit goes to him, all faults are
# mine. K>

import smbus
from time import sleep

# constants of the BMP180 chip from datasheet:
# chip i2c address:
ADDR = 0x77
# maximal conversion time (in seconds):
TMAXTIME = 0.0045
# maximal conversion time (in seconds):
PMAXTIME = (0.0045, 0.0075, 0.0135, 0.0255)
# calibration constants registers adresses:
AC1MSB = 0xAA
AC1LSB = 0xAB
AC2MSB = 0xAC
AC2LSB = 0xAD
AC3MSB = 0xAE
AC3LSB = 0xAF
AC4MSB = 0xB0
AC4LSB = 0xB1
AC5MSB = 0xB2
AC5LSB = 0xB3
AC6MSB = 0xB4
AC6LSB = 0xB5
B1MSB = 0xB6
B1LSB = 0xB7
B2MSB = 0xB8
B2LSB = 0xB9
MBMSB = 0xBA
MBLSB = 0xBB
MCMSB = 0xBC
MCLSB = 0xBD
MDMSB = 0xBE
MDLSB = 0xBF
# start measurement register:
START = 0xF4
# start conversions constants:
TSTART = 0x2E
PSTART = 0x34
# result registers adresses:
RMSB = 0xF6
RLSB = 0xF7
RXLSB = 0xF8


class BMP180(object):
    def __init__(self, rpiversion, acc_mode):  # initialization
        # initialize bus with correct number:
        # for newer version of RPi with 512 MB of RAM set to 1
        # for old one with 256 MB set to 0
        if rpiversion in (0, 1):
            self.bus = smbus.SMBus(1)
        else:
            raise NameError('incorrect rpi version')

        # measurement time safety multiplier:
        self.safety_coeff = 1.1
        # accuracy mode determining pressure measurement time and accuracy:
        # you can set number from 0 to 3.
        # check corect value:
        if not acc_mode in (0, 1, 2, 3):
            # select most accurate mode in the case of bad user input:
            self.acc_mode = 3
        else:
            self.acc_mode = acc_mode

        # read out calibration constants from the chip:
        self.ac1 = (self.bus.read_byte_data(ADDR, AC1MSB) * 256) \
            + self.bus.read_byte_data(ADDR, AC1LSB)
        self.ac2 = (self.bus.read_byte_data(ADDR, AC2MSB) * 256) \
            + self.bus.read_byte_data(ADDR, AC2LSB)
        self.ac3 = (self.bus.read_byte_data(ADDR, AC3MSB) * 256) \
            + self.bus.read_byte_data(ADDR, AC3LSB)
        self.ac4 = (self.bus.read_byte_data(ADDR, AC4MSB) * 256) \
            + self.bus.read_byte_data(ADDR, AC4LSB)
        self.ac5 = (self.bus.read_byte_data(ADDR, AC5MSB) * 256) \
            + self.bus.read_byte_data(ADDR, AC5LSB)
        self.ac6 = (self.bus.read_byte_data(ADDR, AC6MSB) * 256) \
            + self.bus.read_byte_data(ADDR, AC6LSB)

        self.b1 = (self.bus.read_byte_data(ADDR, B1MSB) * 256) \
            + self.bus.read_byte_data(ADDR, B2LSB)
        self.b2 = (self.bus.read_byte_data(ADDR, B2MSB) * 256) \
            + self.bus.read_byte_data(ADDR, B2LSB)

        self.mb = (self.bus.read_byte_data(ADDR, MBMSB) * 256) \
            + self.bus.read_byte_data(ADDR, MBLSB)
        self.mc = (self.bus.read_byte_data(ADDR, MCMSB) * 256) \
            + self.bus.read_byte_data(ADDR, MCLSB)
        self.md = (self.bus.read_byte_data(ADDR, MDMSB) * 256) \
            + self.bus.read_byte_data(ADDR, MDLSB)

        # some calibartion constants are negative hence change to
        # "signed short" type is required:
        if(self.ac1 & 0x8000):
            self.ac1 = -0x10000 + self.ac1
        if(self.ac2 & 0x8000):
            self.ac2 = -0x10000 + self.ac2
        if(self.ac3 & 0x8000):
            self.ac3 = -0x10000 + self.ac3

        if(self.b1 & 0x8000):
            self.b1 = -0x10000 + self.b1
        if(self.b2 & 0x8000):
            self.b2 = -0x10000 + self.b2

        if(self.mb & 0x8000):
            self.mb = -0x10000 + self.mb
        if(self.mc & 0x8000):
            self.mc = -0x10000 + self.mc
        if(self.md & 0x8000):
            self.md = -0x10000 + self.md

    def meas_temp(self):  # measure temperature
        # order to start temperature measurement:
        self.bus.write_byte_data(ADDR, START, TSTART)
        # wait for measurement:
        # maximal measurement time is 4.5 ms:
        sleep(TMAXTIME * self.safety_coeff)
        # read out result registers
        tepmsb = self.bus.read_byte_data(ADDR, RMSB)
        teplsb = self.bus.read_byte_data(ADDR, RLSB)

        # calculate true temperature in degrees of celsius:
        ut = (tepmsb << 8) + teplsb
        x1 = (ut - self.ac6) * self.ac5 / 2 ** 15
        x2 = (self.mc * 2 ** 11) / (x1 + self.md)
        self.b5 = x1 + x2
        self.t = ((self.b5 + 8) / 2 ** 4) / 10.0
        return self.t

    def meas_press(self):  # measure pressure
        # order to start pressure measurement:
        val = PSTART + (self.acc_mode << 6)
        self.bus.write_byte_data(ADDR, START, val)

        # wait for measurement:
        sleep(PMAXTIME[self.acc_mode] * self.safety_coeff)

        # read out result registers:
        tlakmsb = self.bus.read_byte_data(ADDR, RMSB)
        tlaklsb = self.bus.read_byte_data(ADDR, RLSB)
        tlakxlsb = self.bus.read_byte_data(ADDR, RXLSB)

        # calculate absolute pressure:
        # based on algorithm in the catalogue list of BMP180 chip

        up = ((tlakmsb << 16) + (tlaklsb << 8) + tlakxlsb) \
            >> (8 - self.acc_mode)

        b6 = self.b5 - 4000
        x1 = (self.b2 * (b6 * b6 / 2 ** 12)) / 2 ** 11
        x2 = self.ac2 * b6 / 2 ** 11
        x3 = x1 + x2
        b3 = (((self.ac1 * 4 + x3) << self.acc_mode) + 2.0) / 4
        x1 = self.ac3 * b6 / 2 ** 13
        x2 = (self.b1 * (b6 * b6 / 2 ** 12)) / 2 ** 16
        x3 = ((x1 + x2) + 2) / 2 ** 2

        b4 = self.ac4 * (x3 + 32768) / 2 ** 15
        b7 = (up - b3) * (50000 >> self.acc_mode)
        if (b7 < 0x80000000):
            p = (b7 * 2) / b4
        else:
            p = (b7 / b4) * 2

        x1 = (float(p) / 256) * (float(p) / 256)
        x1 = (x1 * 3038) / 2 ** 16
        x2 = (-7357 * p) / 2 ** 16

        self.p = p + (x1 + x2 + 3791) / 2 ** 4
        return self.p

if __name__ == '__main__':  # testing code
    # set RPI version properly!:
    s = BMP180(1, 3)
    # only for information - print out of calibration constants:
    print s.ac1, s.ac2, s.ac3, s.ac4, s.ac5, s.ac6, \
        s.b1, s.b2, s.mb, s.mc, s.md

    # repeatedly measure temperature and pressure and print results:
    while True:
        t = s.meas_temp()
        p = s.meas_press()
        print "{:.2f}".format(t) + " °C,  " + str(p) + " Pa"
        sleep(0.5)

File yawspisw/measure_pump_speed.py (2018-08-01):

#!/usr/bin/env python
# -*- coding: utf-8 -*-
#
# vim modeline: vim: shiftwidth=4 tabstop=4
#
# scritp calculates pumping speed of the source and returns polynomial values
# for yawpi_hw_config.py
#
# you need a measuring glass (ideally of 1 l volume with marks per 0.2 l, if
# not good, change vols list) and source full of water. you will be prompted to
# get ready to fill specified volume. press enter when ready, wait till the
# measuring glass shows the specified volume and pres enter again. empty
# measuring glass. repeat. when finished, copy results to the
# yawpi_hw_config.py

import arrow
import numpy as np
from yawpi_hw_control import yawpihw

h = yawpihw()
vols = [0.2, 0.4, 0.6, 0.8, 1]
times = []
for v in vols:
    print '---------------------------------'
    print 'prepare to fill ' + str(v) + ' l'
    raw_input('press enter when ready')
    print 'Filling ' + str(v) + ' l ...'
    h.st_switch(0, 1)
    h.so_switch(1)
    start = arrow.now('local')
    raw_input('press enter when finished')
    h.so_switch(0)
    h.st_switch(0, 0)
    end = arrow.now('local')
    times.append((end - start).total_seconds())
    print 'total time to fill ' + str(v) + ' l was ' + str(times[-1])

timvec = np.array(times)
volvec = np.array(vols)
# fit model: volume = offset + rate1 * time + rate2 * time
p = np.polyfit(timvec, volvec, 2)
# fit model: time = offset + rate1 * volume + rate2 * volume
pr = np.polyfit(volvec, timvec, 2)
print '================================='
print 'fit to get liters per second:'
print 'slope is: ' + str(p[2])
print 'rate1 is: ' + str(p[1])
print 'rate2 is: ' + str(p[0])
print '---------------------------------'
print 'fit to get seconds for liter'
print 'slope is: ' + str(pr[2])
print 'rate1 is: ' + str(pr[1])
print 'rate2 is: ' + str(pr[0])
print '---------------------------------'
print 'the yawpi_hw_config.py should contain the following lines:'
print '\'FlowRate\': (' + str(p[2]) + ', ' + str(p[1]) + ', ' + str(p[0]) + '),'
print '\'FlowRateRev\': (' + str(pr[2]) + ', ' + str(pr[1]) + ', ' + str(pr[0]) + '),'
print 'as part of the following list (add after such line):'
print 'tmp[\'So\'] = {'

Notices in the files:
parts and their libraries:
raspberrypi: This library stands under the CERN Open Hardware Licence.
